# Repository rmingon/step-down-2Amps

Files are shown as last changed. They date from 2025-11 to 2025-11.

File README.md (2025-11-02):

# Step-Down 2A Buck Regulator

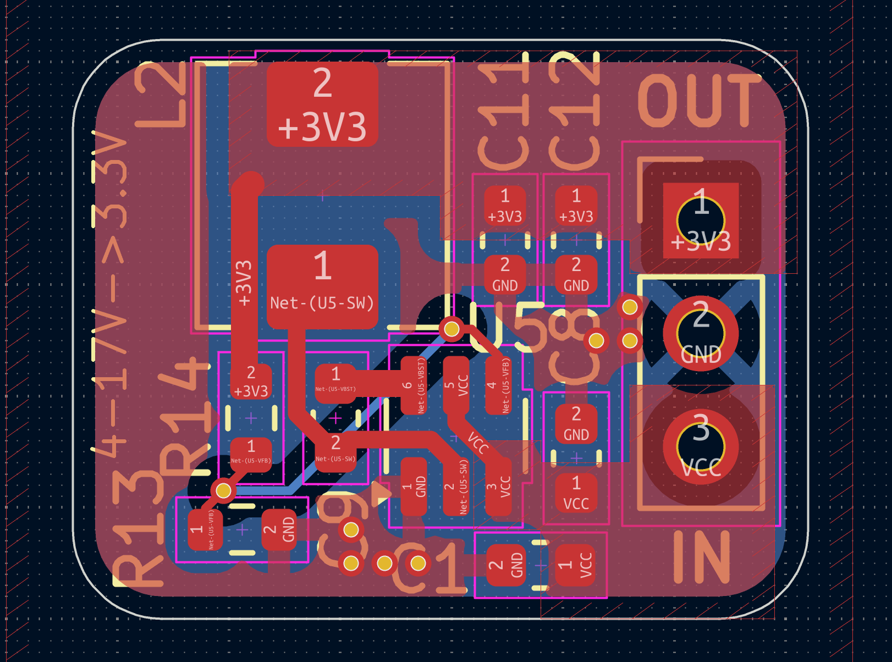
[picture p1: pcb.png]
Board Layout

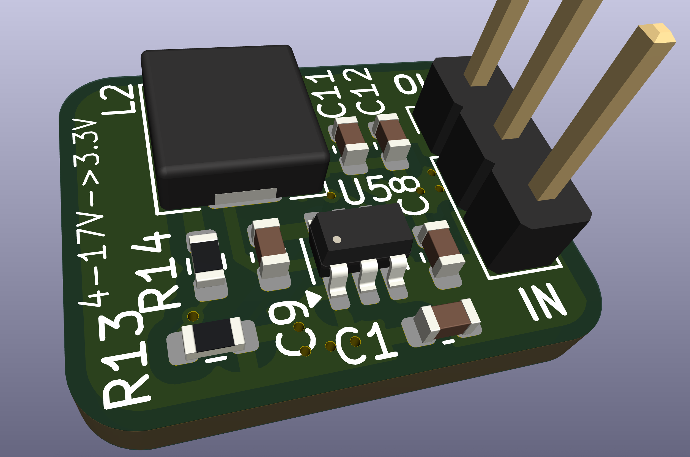
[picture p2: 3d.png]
3D Render

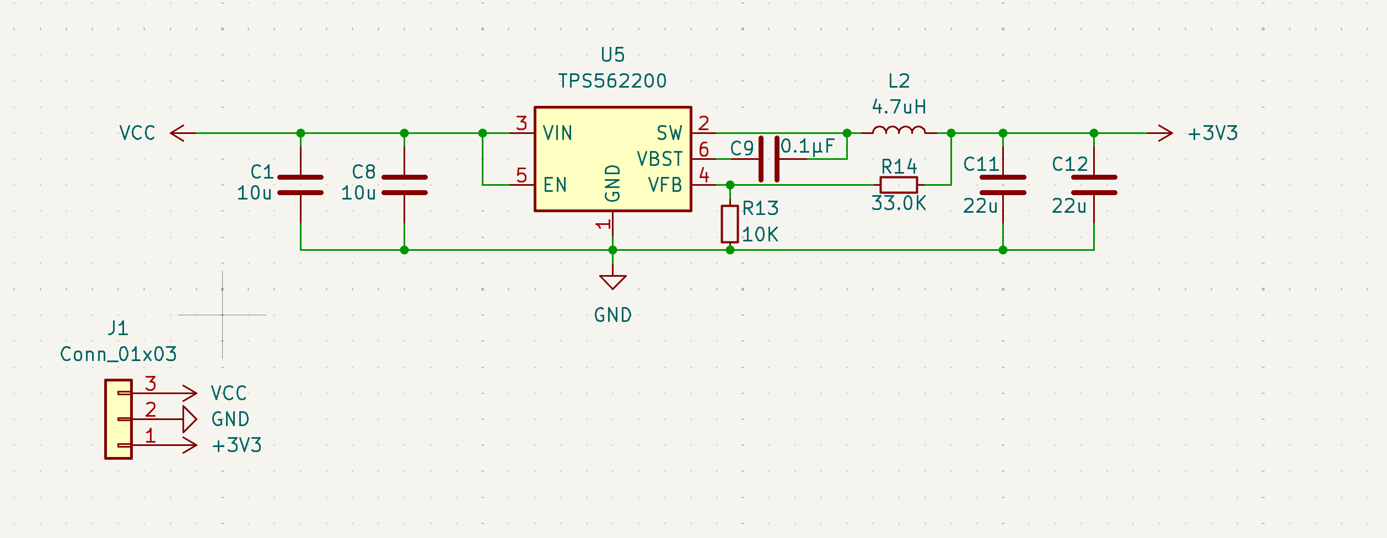
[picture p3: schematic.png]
Schematic


## Overview

- Compact synchronous buck converter built around the TI `TPS562200`, delivering a regulated 3.3 V rail at up to 2 A continuous load.
- Intended as a drop-in power stage for embedded projects that need to step 4.5-17 V sources (battery packs, adapters, backplanes) down to logic-level supplies.
- Three-pin interface exposes the regulated output, return, and raw input for easy wiring or header mounting.

## Electrical Data

- **Input voltage:** 4.5-17 V (per `TPS562200` operating range)
- **Nominal output:** 3.3 V (set by the 33 kOhm / 10 kOhm feedback divider)
- **Continuous current:** up to 2 A with adequate airflow and low-loss layout
- **Switching frequency:** 580 kHz (fixed by controller)

### Pinout (`J1`, from silkscreen Pin 1 marker toward Pin 3)

| Pin | Net  | Function |
| --- | ---- | --- |
| 1 | +3V3 | Regulated 3.3 V output |
| 2 | GND  | Power ground / return |
| 3 | VCC  | Raw input voltage (also feeds `EN`) |

## Repository Contents

- `hardware.kicad_sch`, `hardware.kicad_pcb`: KiCad 8 project files for schematic and board layout.
- `pcb.png`, `3d.png`, `schematic.png`: Quick references for the layout, render, and top-level schematic.

## Assembly Notes

- All passives are 0603 packages.
- `EN` is permanently tied high through the resistor divider, so the regulator starts when `VCC` is present.
- Populate at least one of the 22 uF output capacitors (`C11`, `C12`) for stability; both footprints can be stuffed for additional bulk capacitance.

## Using the Board

1. Solder the three-pin header or wire leads to `J1`.
2. Apply your input source to `VCC`/`GND` and confirm the 3.3 V output on `+3V3`.
3. For different output voltages, adjust the feedback divider (`R14` high-side, `R13` low-side) per the `TPS562200` datasheet (Vout = 0.765 V \* (1 + R14 / R13)).

## License

- Released under the CERN Open Hardware Licence Version 2 - Permissive (`CERN-OHL-P v2`). See `LICENSE` for the full terms and obligations when using the design or producing hardware from it.

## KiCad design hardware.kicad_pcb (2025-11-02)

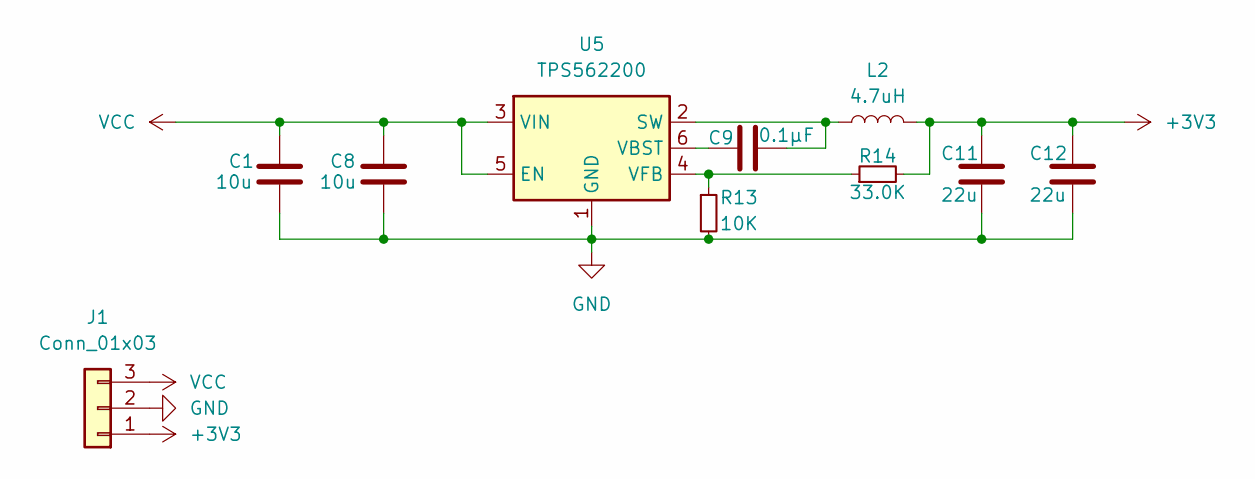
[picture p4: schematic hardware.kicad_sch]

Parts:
C1, C8: 10u; C_0603_1608Metric; LCSC C1691
C9: 0.1µF; C_0603_1608Metric; LCSC C6119867
C11, C12: 22u; C_0603_1608Metric; LCSC C6119867
J1: Conn_01x03; PinHeader_1x03_P2.54mm_Vertical
L2: 4.7uH; L_Chilisin_BMRA00050520; LCSC C3002619
R13: 10K; R_0603_1608Metric; LCSC C25804
R14: 33.0K; R_0603_1608Metric; LCSC C4216
U5: TPS562200; SOT-23-6; LCSC C49757

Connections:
+3V3: C11.1, C12.1, J1.1, L2.2, R14.2
GND: C1.2, C8.2, C11.2, C12.2, J1.2, R13.2, U5.1 (GND)
unnamed: C9.2, L2.1, U5.2 (SW)
unnamed: C9.1, U5.6 (VBST)
unnamed: R13.1, R14.1, U5.4 (VFB)
VCC: C1.1, C8.1, J1.3, U5.3 (VIN), U5.5 (EN)

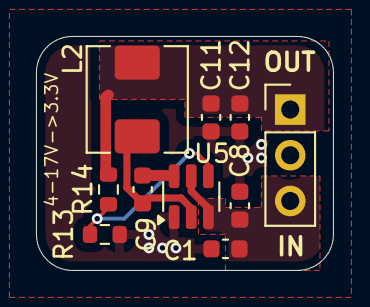
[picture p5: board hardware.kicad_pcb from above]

Board: 2 copper layers, 16.5 x 13.0 mm, 10 parts (0 on the bottom side), 6 nets.
